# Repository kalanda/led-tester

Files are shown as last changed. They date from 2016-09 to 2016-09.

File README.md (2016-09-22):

# Led tester

Device for testing brightness and current consumption of through-hole and SMD LEDs. 

## Mission

With this device you can test any bipolar LEDs and see with your eyes the real brightness and current consumption using a specific resistor value and logic voltage. That's useful because the brightness is different for each color and type of led and this device will help you to choose the right values for your project in a real environment instead of reading the datasheet.

## Features

- Powered with just 4xAA batteries or 6v-12v
- Selector for 5v and 3.3v logic with included voltage regulators
- Terminal connector for multimeter current testing (you need to short this terminals when is not used)
- Valid for SMD and through-hole leds
- Printed silkscreen table with calculated values for each resistor, supply voltage and 'Vf' of the LED
- Selector of current limiting resistor with most common values from 30Ω to 10KΩ

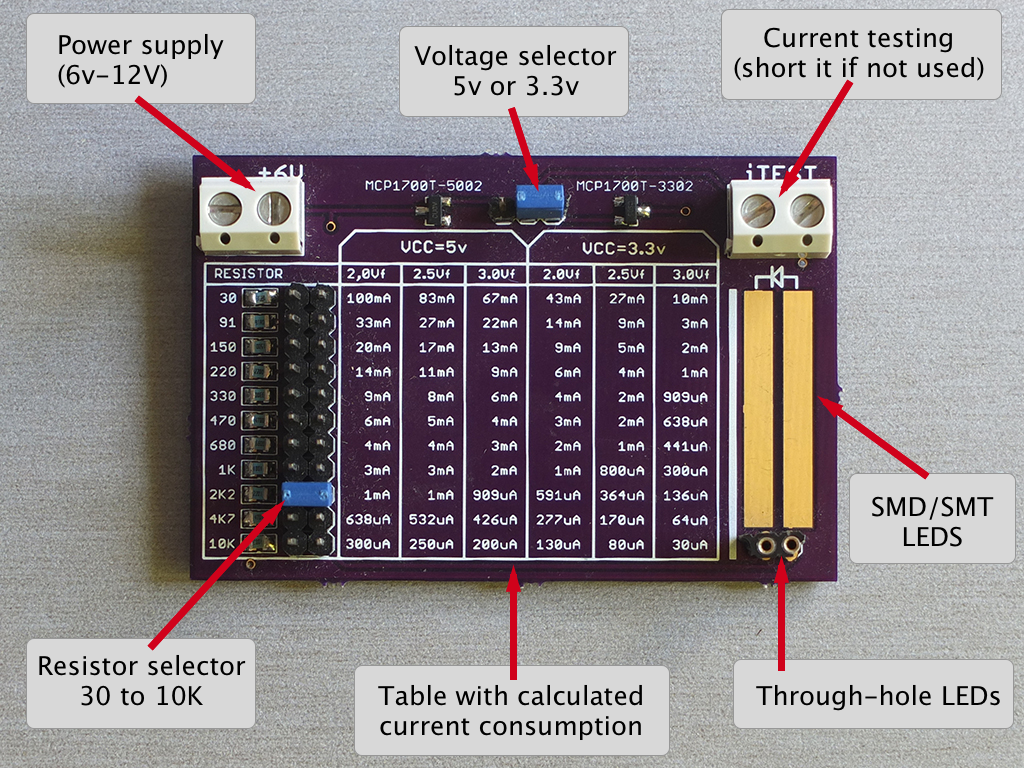
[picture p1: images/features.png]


## Schema and board

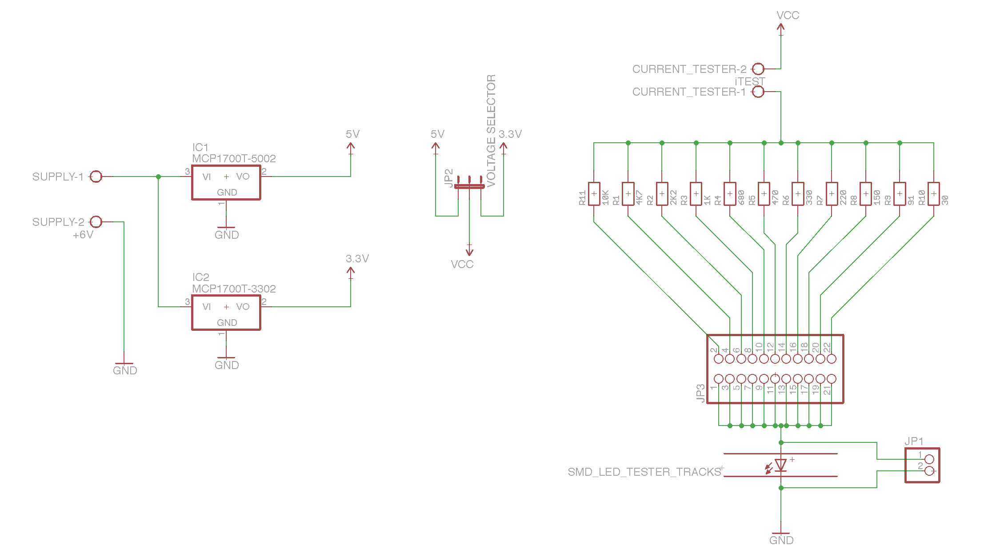
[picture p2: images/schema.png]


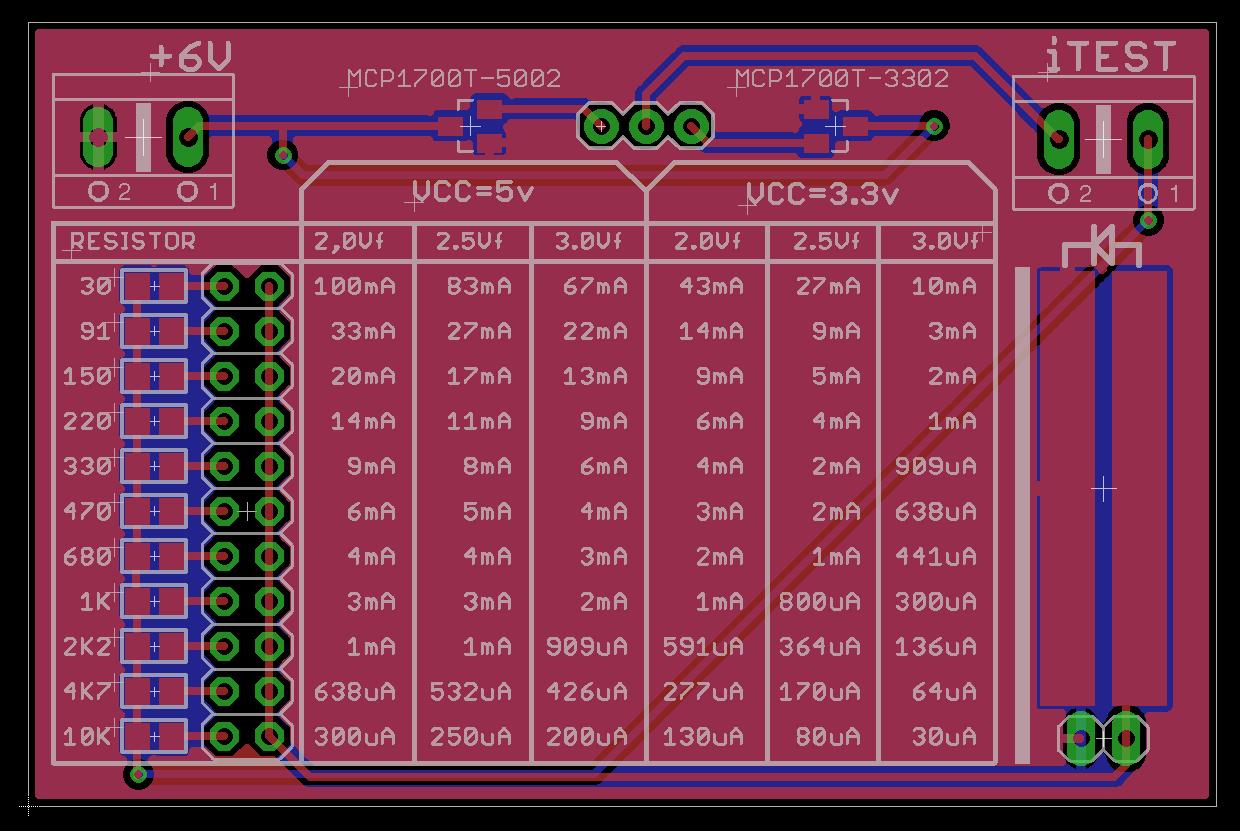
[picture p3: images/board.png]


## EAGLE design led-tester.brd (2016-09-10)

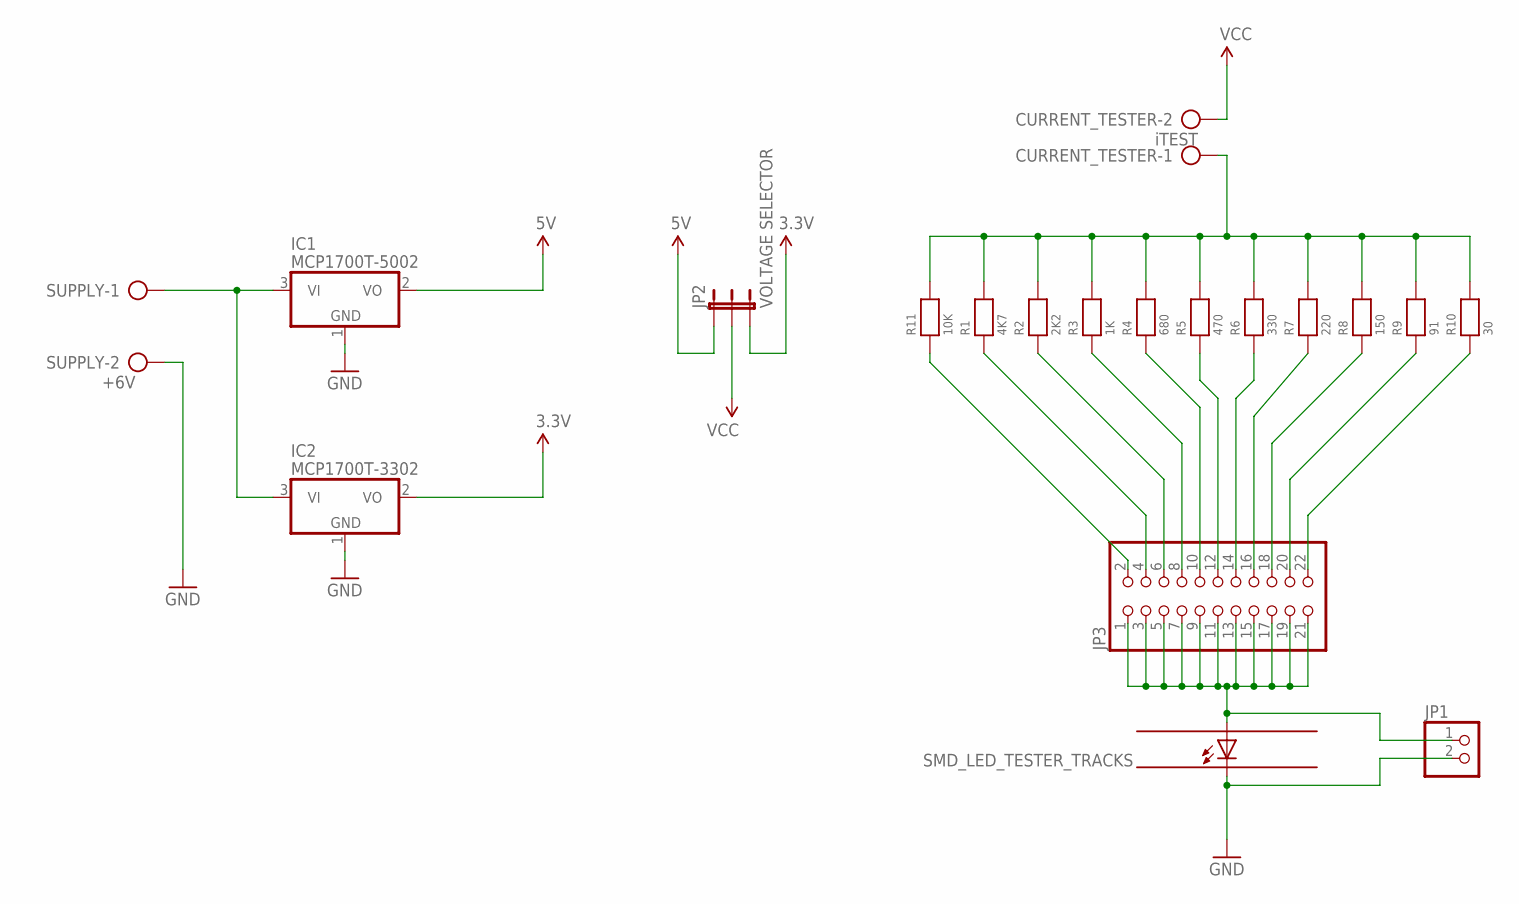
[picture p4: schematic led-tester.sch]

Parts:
CURRENT_TESTER: iTEST; TERMINAL_BLOCK_X2
IC1: MCP1700T-5002; SOT23
IC2: MCP1700T-3302; SOT23
JP1: PINHD-1X2; 1X02
JP2: VOLTAGE SELECTOR; 1X03
JP3: PINHD-2X11; 2X11
R1: 4K7; 0805
R2: 2K2; 0805
R3: 1K; 0805
R4: 680; 0805
R5: 470; 0805
R6: 330; 0805
R7: 220; 0805
R8: 150; 0805
R9: 91; 0805
R10: 30; 0805
R11: 10K; 0805
SUPPLY: +6V; TERMINAL_BLOCK_X2
U$1: SMD_LED_TESTER_TRACKS

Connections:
3.3V: IC2.2 (VO), JP2.3
5V: IC1.2 (VO), JP2.1
GND: IC1.1 (GND), IC2.1 (GND), JP1.2, SUPPLY.2, U$1.P$2 (C)
unnamed: JP3.22, R10.1
unnamed: JP3.20, R9.1
unnamed: JP3.18, R8.1
unnamed: JP3.16, R7.1
unnamed: JP3.14, R6.1
unnamed: JP3.12, R5.1
unnamed: JP3.10, R4.1
unnamed: JP3.8, R3.1
unnamed: JP3.6, R2.1
unnamed: JP3.4, R1.1
unnamed: JP1.1, JP3.1, JP3.3, JP3.5, JP3.7, JP3.9, JP3.11, JP3.13, JP3.15, JP3.17, JP3.19, JP3.21, U$1.P$1 (A)
unnamed: JP3.2, R11.1
unnamed: CURRENT_TESTER.1, R1.2, R2.2, R3.2, R4.2, R5.2, R6.2, R7.2, R8.2, R9.2, R10.2, R11.2
unnamed: IC1.3 (VI), IC2.3 (VI), SUPPLY.1
VCC: CURRENT_TESTER.2, JP2.2

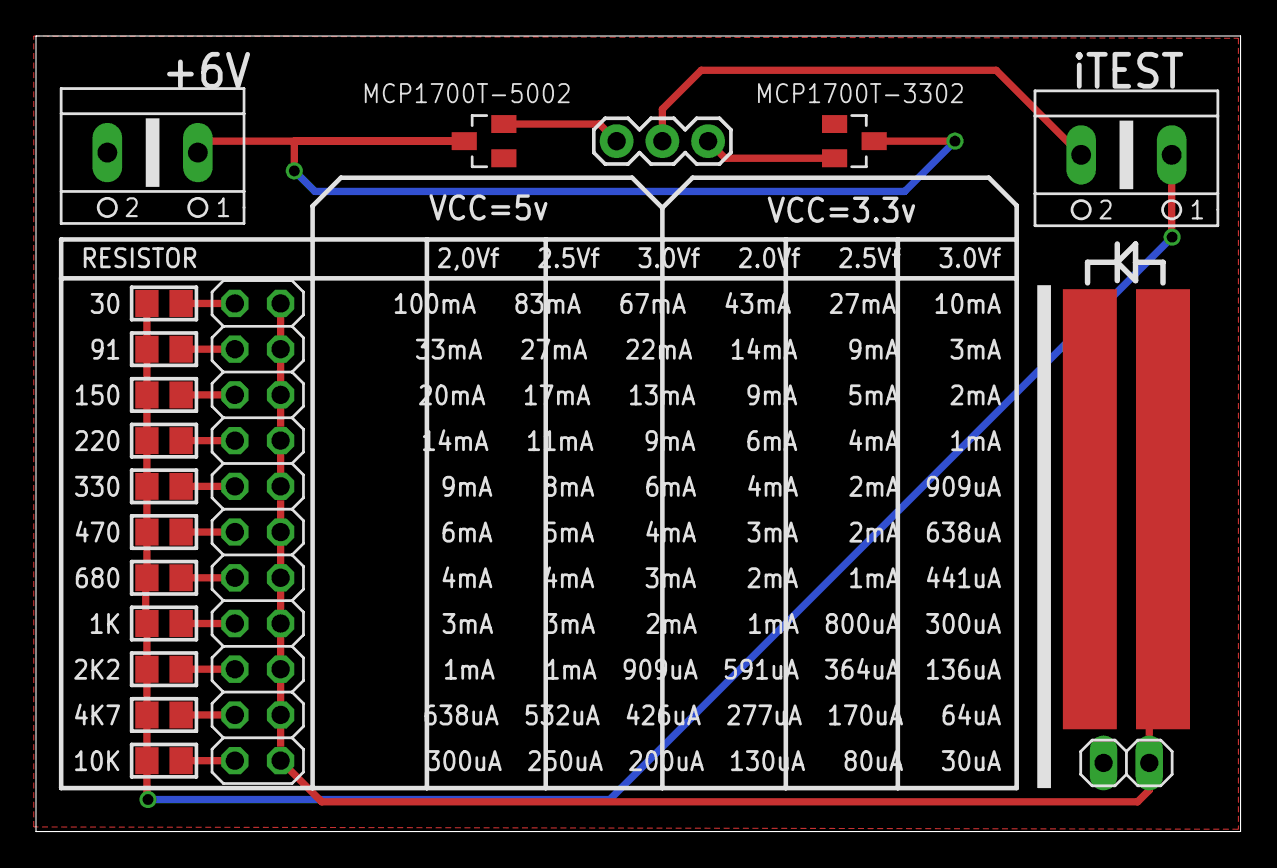
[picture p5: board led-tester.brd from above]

Board: 2 copper layers, 66.9 x 44.2 mm, 19 parts (0 on the bottom side), 18 nets.

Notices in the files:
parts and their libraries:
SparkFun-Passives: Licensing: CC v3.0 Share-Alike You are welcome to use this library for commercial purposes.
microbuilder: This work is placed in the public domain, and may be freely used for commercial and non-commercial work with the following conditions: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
